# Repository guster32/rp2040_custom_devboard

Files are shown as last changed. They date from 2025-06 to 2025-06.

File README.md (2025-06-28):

Screenshot From 2025-06-23 22-47-29

https://datasheets.raspberrypi.com/rp2040/rp2040-datasheet.pdf

https://cdn.sparkfun.com/assets/5/d/3/1/f/hardware-design-with-rp2040.pdf

https://datasheets.raspberrypi.com/rp2040/MinimalKiCAD.zip

https://github.com/sethhillbrand/kicad_templates.git

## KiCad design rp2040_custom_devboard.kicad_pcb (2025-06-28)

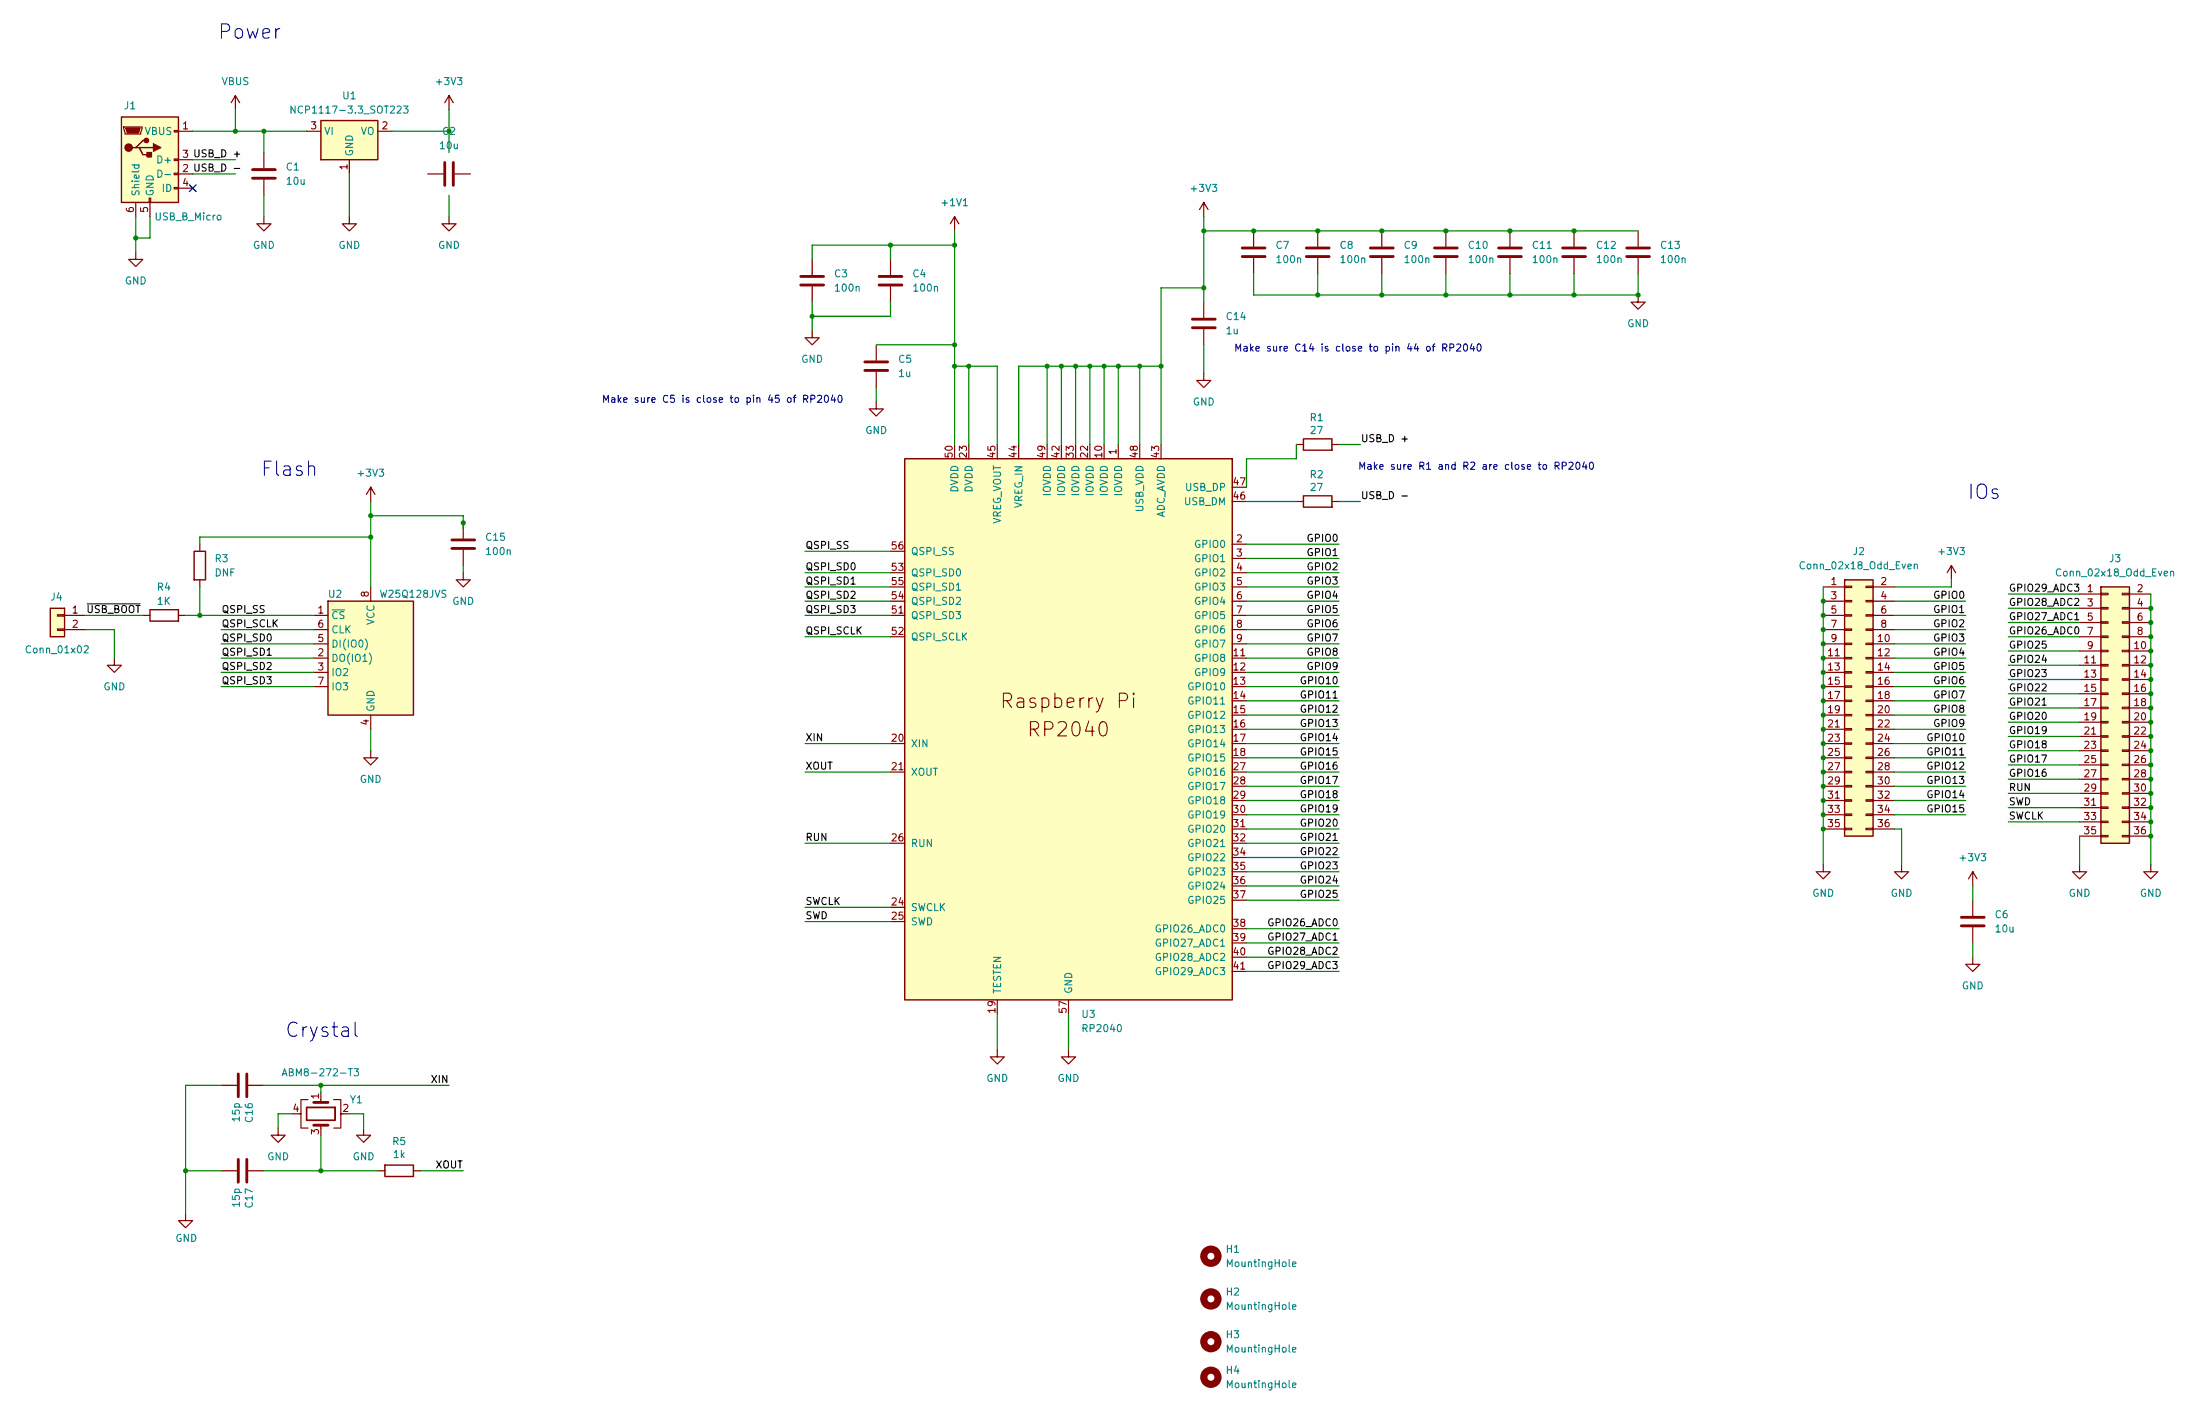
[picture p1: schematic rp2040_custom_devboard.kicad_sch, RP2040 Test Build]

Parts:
C1, C2, C6: 10u; C_0805_2012Metric
C3, C4, C7, C8, C9, C10, C11, C12, C13, C15: 100n; C_0402_1005Metric
C5, C14: 1u; C_0402_1005Metric
C16, C17: 15p; C_0402_1005Metric
H1, H2, H3, H4: MountingHole; MountingHole_2.7mm_M2.5
J1: USB_B_Micro; USB_Micro-B_Amphenol_10103594-0001LF_Horizontal
J2, J3: Conn_02x18_Odd_Even; PinHeader_2x18_P2.54mm_Vertical
J4: Conn_01x02; PinHeader_1x02_P2.54mm_Vertical
R1, R2: 27; R_0402_1005Metric
R3: DNF; R_0402_1005Metric
R4: 1K; R_0402_1005Metric
R5: 1k; R_0402_1005Metric
U1: NCP1117-3.3_SOT223; SOT-223-3_TabPin2
U2: W25Q128JVS; SOIC-8_5.23x5.23mm_P1.27mm
U3: RP2040; RP2040-QFN-56
Y1: ABM8-272-T3; Crystal_SMD_3225-4Pin_3.2x2.5mm

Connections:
+1V1: C3.1, C4.1, C5.1, U3.23 (DVDD), U3.45 (VREG_VOUT), U3.50 (DVDD)
+3V3: C6.1, C7.1, C8.1, C9.1, C10.1, C11.1, C12.1, C13.1, C14.1, C15.1, J2.2, R3.1, U1.2 (VO), U2.8 (VCC), U3.1 (IOVDD), U3.10 (IOVDD), U3.22 (IOVDD), U3.33 (IOVDD), U3.42 (IOVDD), U3.43 (ADC_AVDD), U3.44 (VREG_IN), U3.48 (USB_VDD), U3.49 (IOVDD)
/GPIO0: J2.4, U3.2 (GPIO0)
/GPIO1: J2.6, U3.3 (GPIO1)
/GPIO2: J2.8, U3.4 (GPIO2)
/GPIO3: J2.10, U3.5 (GPIO3)
/GPIO4: J2.12, U3.6 (GPIO4)
/GPIO5: J2.14, U3.7 (GPIO5)
/GPIO6: J2.16, U3.8 (GPIO6)
/GPIO7: J2.18, U3.9 (GPIO7)
/GPIO8: J2.20, U3.11 (GPIO8)
/GPIO9: J2.22, U3.12 (GPIO9)
/GPIO10: J2.24, U3.13 (GPIO10)
/GPIO11: J2.26, U3.14 (GPIO11)
/GPIO12: J2.28, U3.15 (GPIO12)
/GPIO13: J2.30, U3.16 (GPIO13)
/GPIO14: J2.32, U3.17 (GPIO14)
/GPIO15: J2.34, U3.18 (GPIO15)
/GPIO16: J3.27, U3.27 (GPIO16)
/GPIO17: J3.25, U3.28 (GPIO17)
/GPIO18: J3.23, U3.29 (GPIO18)
/GPIO19: J3.21, U3.30 (GPIO19)
/GPIO20: J3.19, U3.31 (GPIO20)
/GPIO21: J3.17, U3.32 (GPIO21)
/GPIO22: J3.15, U3.34 (GPIO22)
/GPIO23: J3.13, U3.35 (GPIO23)
/GPIO24: J3.11, U3.36 (GPIO24)
/GPIO25: J3.9, U3.37 (GPIO25)
/GPIO26_ADC0: J3.7, U3.38 (GPIO26_ADC0)
/GPIO27_ADC1: J3.5, U3.39 (GPIO27_ADC1)
/GPIO28_ADC2: J3.3, U3.40 (GPIO28_ADC2)
/GPIO29_ADC3: J3.1, U3.41 (GPIO29_ADC3)
/QSPI_SCLK: U2.6 (CLK), U3.52 (QSPI_SCLK)
/QSPI_SD0: U2.5 (DI(IO0)), U3.53 (QSPI_SD0)
/QSPI_SD1: U2.2 (DO(IO1)), U3.55 (QSPI_SD1)
/QSPI_SD2: U2.3 (IO2), U3.54 (QSPI_SD2)
/QSPI_SD3: U2.7 (IO3), U3.51 (QSPI_SD3)
/QSPI_SS: R3.2, R4.2, U2.1 (~CS), U3.56 (QSPI_SS)
/RUN: J3.29, U3.26 (RUN)
/SWCLK: J3.33, U3.24 (SWCLK)
/SWD: J3.31, U3.25 (SWD)
/USB_D +: J1.3 (D+), R1.2
/USB_D -: J1.2 (D-), R2.2
/XIN: C16.1, U3.20 (XIN), Y1.1
/XOUT: R5.1, U3.21 (XOUT)
/~USB_BOOT: J4.1, R4.1
GND: C1.2, C3.2, C4.2, C5.2, C6.2, C7.2, C8.2, C9.2, C10.2, C11.2, C12.2, C13.2, C14.2, C15.2, C16.2, C17.2, J1.5 (GND), J1.6 (Shield), J2.1, J2.3, J2.5, J2.7, J2.9, J2.11, J2.13, J2.15, J2.17, J2.19, J2.21, J2.23, J2.25, J2.27, J2.29, J2.31, J2.33, J2.35, J2.36, J3.2, J3.4, J3.6, J3.8, J3.10, J3.12, J3.14, J3.16, J3.18, J3.20, J3.22, J3.24, J3.26, J3.28, J3.30, J3.32, J3.34, J3.35, J3.36, J4.2, U1.1 (GND), U2.4 (GND), U3.19 (TESTEN), U3.57 (GND), Y1.2, Y1.4
unnamed: C17.1, R5.2, Y1.3
unnamed: R2.1, U3.46 (USB_DM)
unnamed: R1.1, U3.47 (USB_DP)
VBUS: C1.1, J1.1 (VBUS), U1.3 (VI)

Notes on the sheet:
Power
IOs
Make sure C14 is close to pin 44 of RP2040
Crystal
Make sure R1 and R2 are close to RP2040
Make sure C5 is close to pin 45 of RP2040
Flash

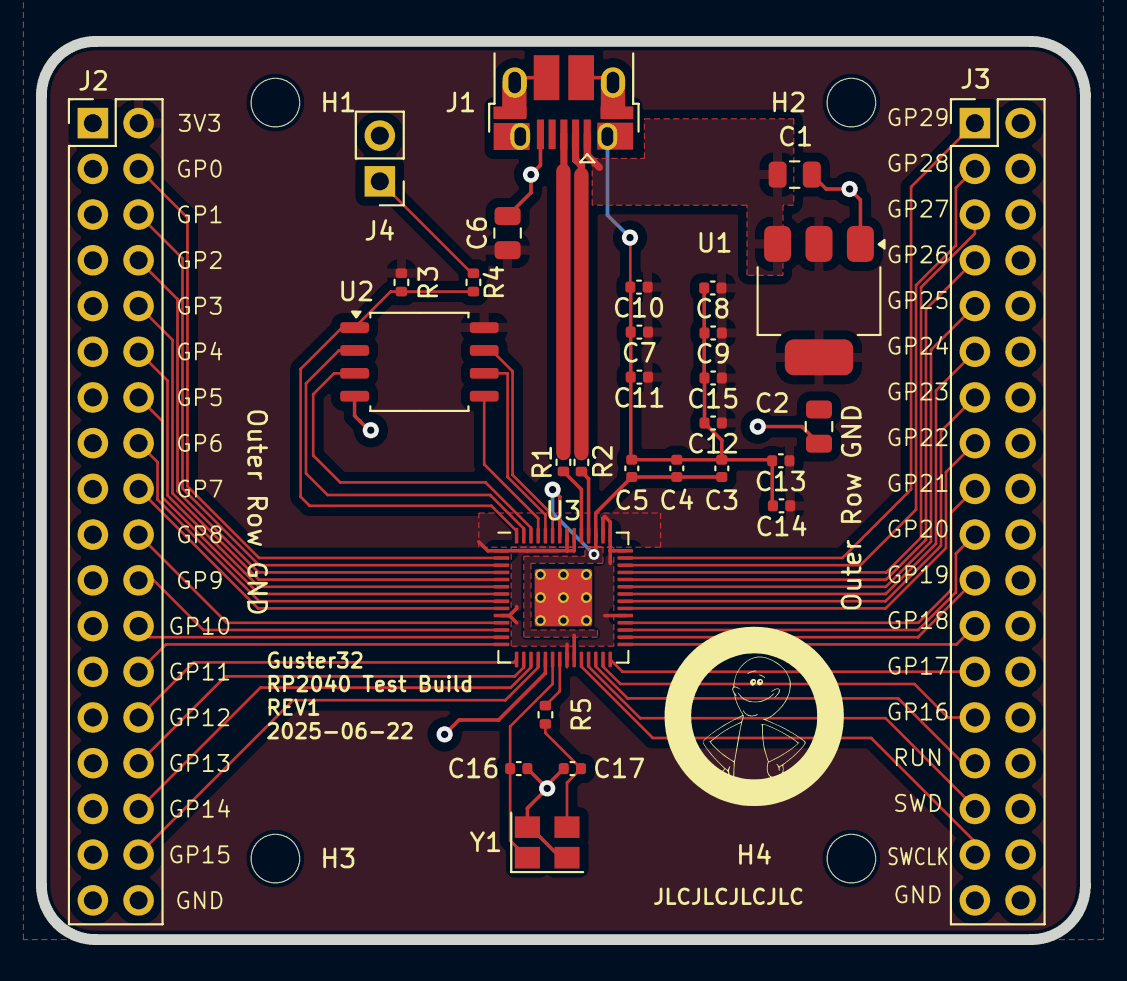
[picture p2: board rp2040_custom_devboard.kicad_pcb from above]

Board: 4 copper layers, 58.0 x 49.9 mm, 34 parts (0 on the bottom side), 51 nets.
